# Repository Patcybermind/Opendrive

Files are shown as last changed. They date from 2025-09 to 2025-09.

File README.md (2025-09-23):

# Opendrive
This is currently the first prototype for a open source Field-Oriented Control Electronic Speed Controller.

I am currently designing it to be able to drive 300w motors at 12v (or 3s).

This doesnt mean these are limitation. With good cooling they should be able to handle quite a bit more.

It's designed to be used on a robotic arm I'm working on.

For Groundplane:
the template gives a 404

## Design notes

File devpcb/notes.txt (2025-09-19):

-55℃~+150℃ 1 N-Channel 100V 135A 2.5V 225W 27pF@25V 3.95nF 4.5mΩ@4.5V,20A 67nC@50V TO-220 MOSFETs ROHS
is the mosfet planned (pulled from https://jlcpcb.com/parts/componentSearch?searchTxt=IRFB4110PbF)
RS100N135T is the name

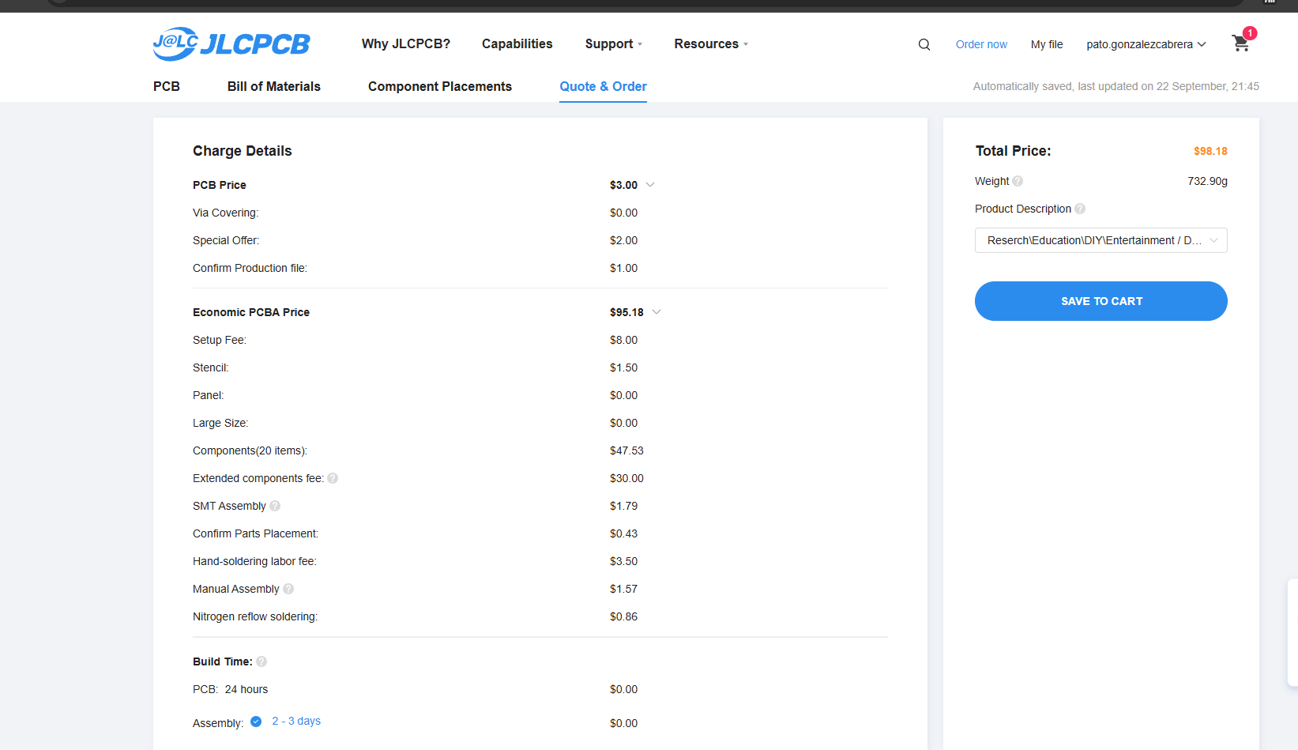
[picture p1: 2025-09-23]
cart.png

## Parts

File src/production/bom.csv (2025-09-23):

Designator | Footprint | Quantity | Value | LCSC Part #
C1, C10, C11, C2, C22, C3, C4, C5, C6, C8 | 0402 | 10 | 100n
C12 | 0402 | 1 | 0.022µF
C13 | 0805 | 1 | 2.2µF
C14, C15 | 0603 | 2 | 1µF
C16 | 0805 | 1 | 4.7µF
C17, C18, C19 | 0603 | 3 | 0.1µF
C20, C21 | 0805 | 2 | 10u
C23, C24 | 0402 | 2 | 15p
C7, C9 | 0603 | 2 | 1u
J1, J2 | PinHeader_1x03_P2.54mm_Vertical | 2 | Conn_01x03_Pin
J3 | USB_Micro-AB_Molex_47590-0001 | 1 | USB_B_Micro
J4, J5, J6, J7 | PinHeader_1x02_P2.54mm_Vertical | 4 | Conn_01x02_Pin
J8, J9 | PinHeader_1x20_P2.54mm_Vertical | 2 | Conn_01x20_Pin
R1, R2 | 0402 | 2 | 27.4
R10, R11, R12, R5, R6, R7 | 0402 | 6 | 15
R13, R15 | 0402 | 2 | 1k
R14 | 0402 | 1 | DNF
R3, R4, R9 | 0402 | 3 | 10k
R8 | 0402 | 1 | 33k
U1 | DCA56_6P35X3P61 | 1 | DRV8301DCAR
U10 | SOIC-8_5.3x5.3mm_P1.27mm | 1 | W25Q128JVS
U2 | QFN-56-1EP_7x7mm_P0.4mm_EP3.2x3.2mm | 1 | RP2040
U3, U4, U5, U6, U7, U8 | TO-220-3_Vertical | 6 | ~
U9 | SOT-223-3_TabPin2 | 1 | NCP1117-3.3_SOT223
Y1 | Crystal_SMD_3225-4Pin_3.2x2.5mm | 1 | Crystal_GND23

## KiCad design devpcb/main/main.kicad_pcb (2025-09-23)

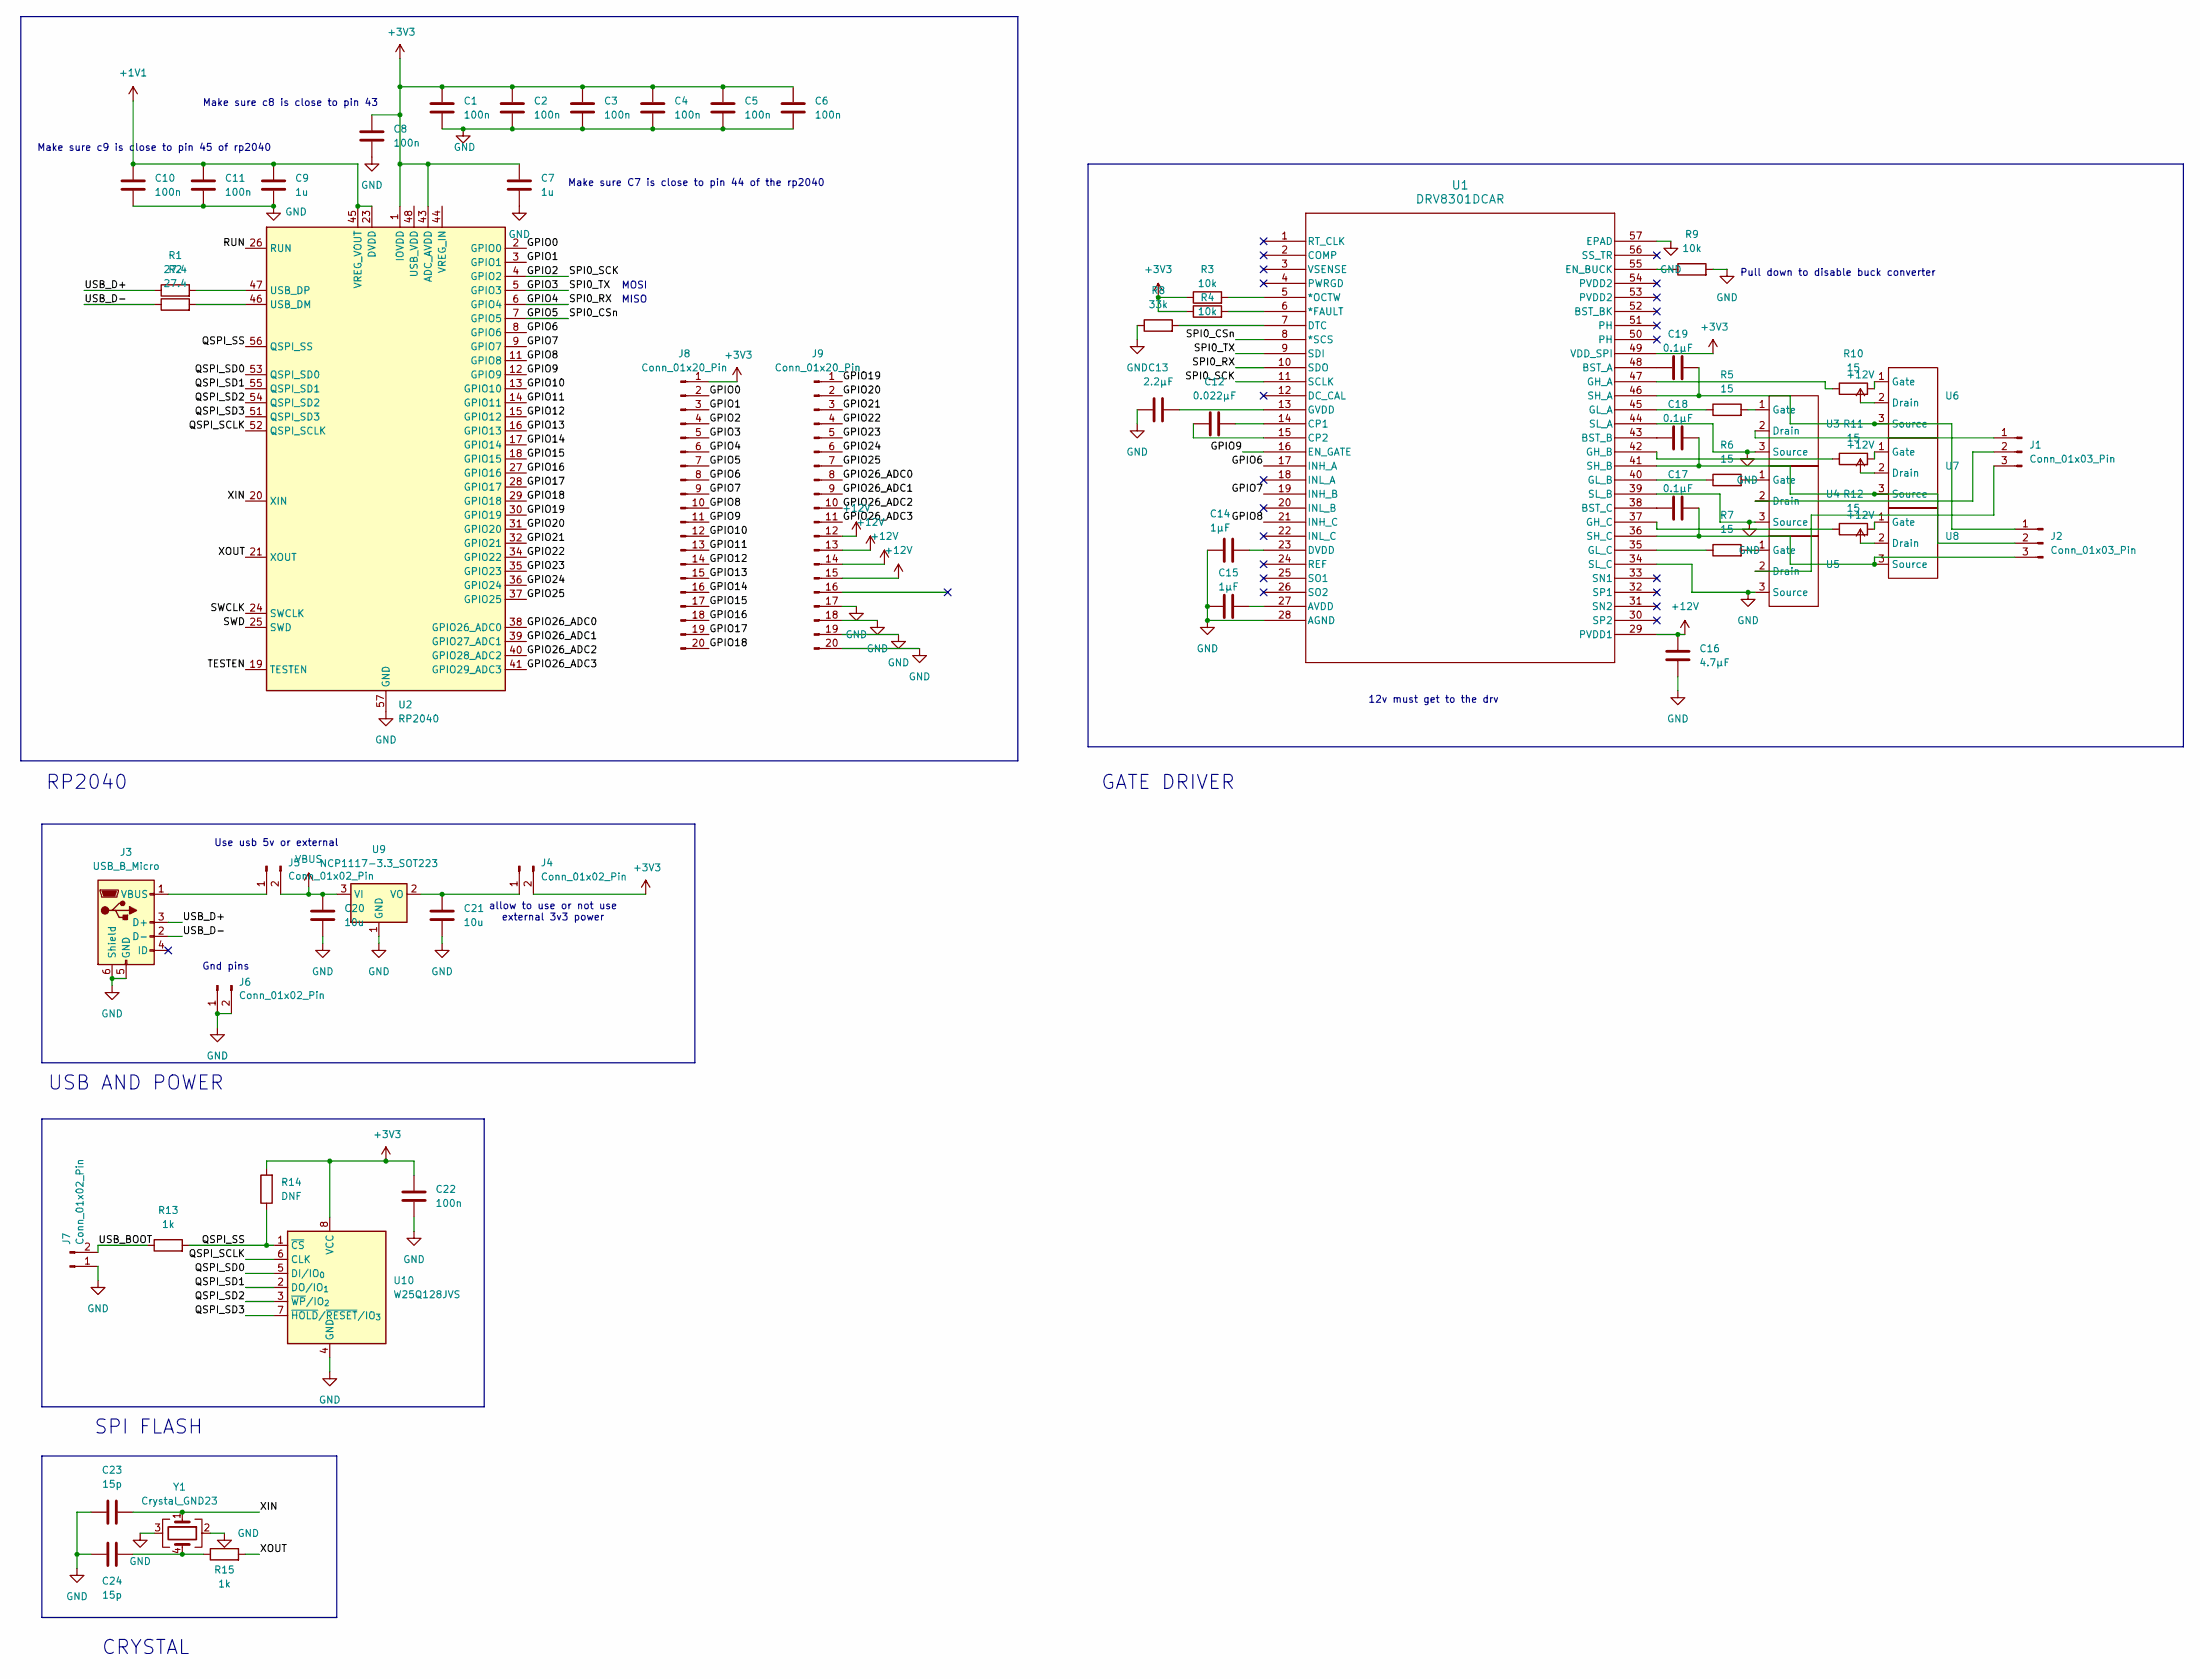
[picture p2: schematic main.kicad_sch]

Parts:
C1, C2, C3, C4, C5, C6, C8, C10, C11, C22: 100n; C_0402_1005Metric
C7, C9: 1u; C_0603_1608Metric
C12: 0.022µF; C_0402_1005Metric_Pad0.74x0.62mm_HandSolder
C13: 2.2µF; C_0805_2012Metric
C14, C15: 1µF; C_0603_1608Metric
C16: 4.7µF; C_0805_2012Metric
C17, C18, C19: 0.1µF; C_0603_1608Metric
C20, C21: 10u; C_0805_2012Metric
C23, C24: 15p; C_0402_1005Metric
J1, J2: Conn_01x03_Pin; PinHeader_1x03_P2.54mm_Vertical
J3: USB_B_Micro; USB_Micro-AB_Molex_47590-0001
J4, J5, J6, J7: Conn_01x02_Pin; PinHeader_1x02_P2.54mm_Vertical
J8, J9: Conn_01x20_Pin; PinHeader_1x20_P2.54mm_Vertical
R1, R2: 27.4; R_0402_1005Metric
R3, R4, R9: 10k; R_0402_1005Metric
R5, R6, R7, R10, R11, R12: 15; R_0402_1005Metric
R8: 33k; R_0402_1005Metric
R13, R15: 1k; R_0402_1005Metric
R14: DNF; R_0402_1005Metric
U1: DRV8301DCAR; DCA56_6P35X3P61
U2: RP2040; QFN-56-1EP_7x7mm_P0.4mm_EP3.2x3.2mm
U3, U4, U5, U6, U7, U8: TO-220-3_Vertical
U9: NCP1117-3.3_SOT223; SOT-223-3_TabPin2
U10: W25Q128JVS; SOIC-8_5.3x5.3mm_P1.27mm
Y1: Crystal_GND23; Crystal_SMD_3225-4Pin_3.2x2.5mm

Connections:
+1V1: C9.1, C10.1, C11.1, U2.23 (DVDD), U2.45 (VREG_VOUT), U2.50 (DVDD)
+3V3: C1.1, C2.1, C3.1, C4.1, C5.1, C6.1, C7.1, C8.1, C22.1, J4.2, J8.1, R3.1, R4.1, R14.2, U1.49 (VDD_SPI), U2.1 (IOVDD), U2.10 (IOVDD), U2.22 (IOVDD), U2.33 (IOVDD), U2.42 (IOVDD), U2.43 (ADC_AVDD), U2.49 (IOVDD), U10.8 (VCC)
+12V: C16.1, J9.12, J9.13, J9.14, J9.15, U1.29 (PVDD1), U6.2 (Drain), U7.2 (Drain), U8.2 (Drain)
/GPIO0: J8.2, U2.2 (GPIO0)
/GPIO1: J8.3, U2.3 (GPIO1)
/GPIO2: J8.4, U1.11 (SCLK), U2.4 (GPIO2)
/GPIO3: J8.5, U1.9 (SDI), U2.5 (GPIO3)
/GPIO4: J8.6, U1.10 (SDO), U2.6 (GPIO4)
/GPIO5: J8.7, U1.8 (*SCS), U2.7 (GPIO5)
/GPIO6: J8.8, U1.17 (INH_A), U2.8 (GPIO6)
/GPIO7: J8.9, U1.19 (INH_B), U2.9 (GPIO7)
/GPIO8: J8.10, U1.21 (INH_C), U2.11 (GPIO8)
/GPIO9: J8.11, U1.16 (EN_GATE), U2.12 (GPIO9)
/GPIO10: J8.12, U2.13 (GPIO10)
/GPIO11: J8.13, U2.14 (GPIO11)
/GPIO12: J8.14, U2.15 (GPIO12)
/GPIO13: J8.15, U2.16 (GPIO13)
/GPIO14: J8.16, U2.17 (GPIO14)
/GPIO15: J8.17, U2.18 (GPIO15)
/GPIO16: J8.18, U2.27 (GPIO16)
/GPIO17: J8.19, U2.28 (GPIO17)
/GPIO18: J8.20, U2.29 (GPIO18)
/GPIO19: J9.1, U2.30 (GPIO19)
/GPIO20: J9.2, U2.31 (GPIO20)
/GPIO21: J9.3, U2.32 (GPIO21)
/GPIO22: J9.4, U2.34 (GPIO22)
/GPIO23: J9.5, U2.35 (GPIO23)
/GPIO24: J9.6, U2.36 (GPIO24)
/GPIO25: J9.7, U2.37 (GPIO25)
/GPIO26_ADC0: J9.8, U2.38 (GPIO26_ADC0)
/GPIO26_ADC1: J9.9, U2.39 (GPIO27_ADC1)
/GPIO26_ADC2: J9.10, U2.40 (GPIO28_ADC2)
/GPIO26_ADC3: J9.11, U2.41 (GPIO29_ADC3)
/QSPI_SCLK: U2.52 (QSPI_SCLK), U10.6 (CLK)
/QSPI_SD0: U2.53 (QSPI_SD0), U10.5 (DI/IO_{0})
/QSPI_SD1: U2.55 (QSPI_SD1), U10.2 (DO/IO_{1})
/QSPI_SD2: U2.54 (QSPI_SD2), U10.3 (~WP/IO_{2})
/QSPI_SD3: U2.51 (QSPI_SD3), U10.7 (~HOLD/~RESET/IO_{3})
/QSPI_SS: R13.2, R14.1, U2.56 (QSPI_SS), U10.1 (~CS)
/RUN: U2.26 (RUN)
/SWCLK: U2.24 (SWCLK)
/SWD: U2.25 (SWD)
/TESTEN: U2.19 (TESTEN)
/USB_BOOT: J7.2, R13.1
/USB_D+: J3.3 (D+), R1.1
/USB_D-: J3.2 (D-), R2.1
/XIN: C23.2, U2.20 (XIN), Y1.1
/XOUT: R15.2, U2.21 (XOUT)
GND: C1.2, C2.2, C3.2, C4.2, C5.2, C6.2, C7.2, C8.2, C9.2, C10.2, C11.2, C13.1, C14.1, C15.1, C16.2, C20.2, C21.2, C22.2, C23.1, C24.1, J3.5 (GND), J3.6 (Shield), J6.1, J6.2, J7.1, J9.17, J9.18, J9.19, J9.20, R8.1, R9.2, U1.28 (AGND), U1.34 (SL_C), U1.39 (SL_B), U1.44 (SL_A), U1.57 (EPAD), U2.57 (GND), U3.3 (Source), U4.3 (Source), U5.3 (Source), U9.1 (GND), U10.4 (GND), Y1.2, Y1.3
unnamed: C24.2, R15.1, Y1.4
unnamed: J1.1, U3.2 (Drain)
unnamed: J1.2, U4.2 (Drain)
unnamed: J1.3, U5.2 (Drain)
unnamed: C19.2, J2.1, U1.46 (SH_A), U6.3 (Source)
unnamed: C18.2, J2.2, U1.41 (SH_B), U7.3 (Source)
unnamed: C17.2, J2.3, U1.36 (SH_C), U8.3 (Source)
unnamed: J3.1 (VBUS), J5.1
unnamed: C21.1, J4.1, U9.2 (VO)
unnamed: R4.2, U1.6 (*FAULT)
unnamed: R3.2, U1.5 (*OCTW)
unnamed: C15.2, U1.27 (AVDD)
unnamed: C19.1, U1.48 (BST_A)
unnamed: C18.1, U1.43 (BST_B)
unnamed: C17.1, U1.38 (BST_C)
unnamed: C12.2, U1.14 (CP1)
unnamed: C12.1, U1.15 (CP2)
unnamed: R8.2, U1.7 (DTC)
unnamed: C14.2, U1.23 (DVDD)
unnamed: R9.1, U1.55 (EN_BUCK)
unnamed: R10.1, U1.47 (GH_A)
unnamed: R11.1, U1.42 (GH_B)
unnamed: R12.1, U1.37 (GH_C)
unnamed: R5.1, U1.45 (GL_A)
unnamed: R6.1, U1.40 (GL_B)
unnamed: R7.1, U1.35 (GL_C)
unnamed: C13.2, U1.13 (GVDD)
unnamed: R2.2, U2.46 (USB_DM)
unnamed: R1.2, U2.47 (USB_DP)
unnamed: R5.2, U3.1 (Gate)
unnamed: R6.2, U4.1 (Gate)
unnamed: R7.2, U5.1 (Gate)
unnamed: R10.2, U6.1 (Gate)
unnamed: R11.2, U7.1 (Gate)
unnamed: R12.2, U8.1 (Gate)
VBUS: C20.1, J5.2, U9.3 (VI)

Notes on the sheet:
allow to use or not use external 3v3 power
Use usb 5v or external
MOSI
SPI FLASH
12v must get to the drv
GATE DRIVER
USB AND POWER
CRYSTAL
Gnd pins
Make sure c8 is close to pin 43
Pull down to disable buck converter
RP2040
MISO
Make sure c9 is close to pin 45 of rp2040
Make sure C7 is close to pin 44 of the rp2040

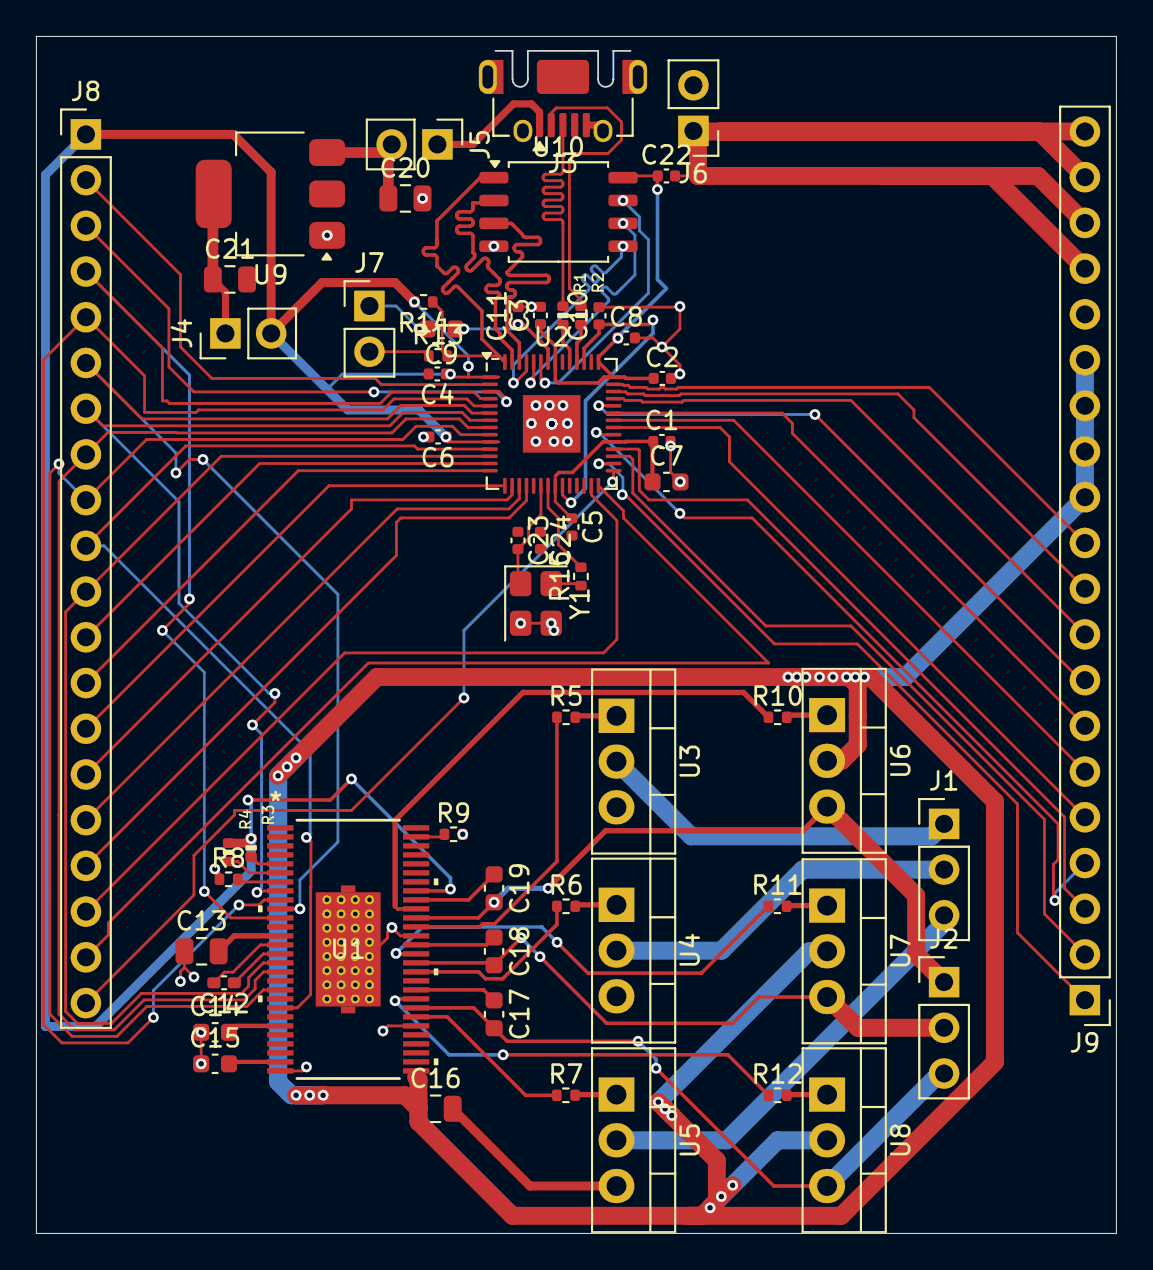
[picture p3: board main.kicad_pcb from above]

Board: 2 copper layers, 60.0 x 66.5 mm, 59 parts (0 on the bottom side), 81 nets.

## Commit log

2025-09-16 7 51 sept 16
    [main.kicad_pcb, main.kicad_sch]
2025-09-19 sep 18 gn
    [main.kicad_sch]
2025-09-19 gtg sep 19 5pm
    [main.kicad_pcb, main.kicad_sch]
